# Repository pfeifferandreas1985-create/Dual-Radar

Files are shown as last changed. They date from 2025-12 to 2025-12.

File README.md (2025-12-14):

# NERO SENSE - Dual Radar System

**Nero Sense** is a high-tech, dual-system radar dashboard designed for environmental scanning and visualization. It combines an Ultrasonic Radar (System A) and a TOF Lidar (System B) into a unified "Tactical Dashboard" web interface.

## 🚀 Features

*   **Dual System Support**:
    *   **System A (Ultrasonic)**: Long-range, multi-sensor scanning (HC-SR04).
    *   **System B (TOF Lidar)**: High-precision, fast scanning (VL53L1X) with local display.
*   **Tactical Dashboard**: A futuristic web interface (HTML5/Canvas) featuring:
    *   **TRON & Matrix Themes**: Distinct visual styles for each system.
    *   **Real-time Visualization**: Smooth radar sweep, persistent object detection, and fading trails.
    *   **Dynamic Scaling**: Adjustable range controls (Zoom).
    *   **Telemetry**: Live distance and angle readouts.
*   **Hybrid Mode (System B)**: The TOF unit operates as a standalone device with a local **GC9A01 Circular Display**, showing a "Tactical Grid" and data even without WiFi.

---

## 🛠 Hardware & Wiring

### System B: TOF Lidar (Hybrid Unit)
*   **MCU**: Wemos D1 Mini (ESP8266)
*   **Sensor**: VL53L1X (TOF0400)
*   **Display**: 1.28" GC9A01 Circular TFT (240x240)
*   **Actuator**: Micro Servo (SG90)

#### Wiring Diagram
| Component | Pin | Wemos D1 Mini (GPIO) |
| :--- | :--- | :--- |
| **GC9A01** | **SCLK** | **D5** (GPIO 14) |
| | **MOSI** | **D7** (GPIO 13) |
| | **CS** | **D8** (GPIO 15) |
| | **DC** | **D3** (GPIO 0) |
| | **RST** | **D0** (GPIO 16) |
| | **VCC** | 3.3V |
| | **GND** | GND |
| **VL53L1X** | **SDA** | **D2** (GPIO 4) |
| | **SCL** | **D1** (GPIO 5) |
| | **VCC** | 3.3V |
| | **GND** | GND |
| **Servo** | **Signal** | **D6** (GPIO 12) |
| | **VCC** | 5V |
| | **GND** | GND |

---

## 💾 Firmware Installation

### Prerequisites
1.  **Arduino IDE**: Install the latest version.
2.  **ESP8266 Board Manager**: Install `esp8266` by ESP8266 Community.
3.  **Libraries**: Install via Library Manager:
    *   `TFT_eSPI` by Bodmer
    *   `VL53L1X` by Pololu
    *   `WebSockets` by Markus Sattler
    *   `Servo` (Built-in)

### Configuration (Critical!)
You **MUST** configure the `TFT_eSPI` library to work with the GC9A01 and Wemos D1 Mini pins.
1.  Go to your Arduino libraries folder: `Documents/Arduino/libraries/TFT_eSPI/`
2.  Edit `User_Setup.h`.
3.  Replace its content with the settings found in: `Firmware/Nereo_Sense_Hybrid_Wemos/User_Setup_Wemos.txt`

### Uploading
1.  Open `Firmware/Nereo_Sense_Hybrid_Wemos/Nero_Sense_Hybrid_Wemos.ino`.
2.  Set your WiFi SSID and Password in the code (if not already set).
3.  Select Board: **LOLIN(WEMOS) D1 R2 & mini**.
4.  Upload!

---

## 🖥️ Dashboard Usage

1.  **Open the Dashboard**: Open `Software/Dashboard/TRON_Radar.html` in any modern web browser.
2.  **Connect**:
    *   Enter the IP address of System A (Default: `192.168.178.70`).
    *   Enter the IP address of System B (Default: `192.168.178.41`).
    *   Click **CONNECT**.
3.  **Controls**:
    *   **Range**: Adjust the input field (e.g., "50" cm or "1000" mm) to zoom in/out.
    *   **Visuals**: Enjoy the show!

---

## 📂 Repository Structure

*   `Docs/`: Documentation files.
*   `Firmware/`: Arduino source code.
    *   `Nereo_Sense_Hybrid_Wemos/`: Firmware for System B (TOF).
    *   `LidarRadar/`: Firmware for System A (Ultrasonic).
*   `Hardware/`: CAD files and 3D models.
*   `Software/`: PC-side software.
    *   `Dashboard/`: The HTML5 Web Interface.

---

**Nero Sense Project** - *Advanced Environmental Awareness*

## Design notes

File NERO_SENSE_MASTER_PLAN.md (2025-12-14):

# NERO SENSE - MASTER PLAN
**System Architecture & Future Roadmap**

## 🟢 Variante 1: Das Aktuelle System (Scanning Lidar)
**Status: Operational**

Ein Sensor auf einem Servo, der die Umgebung abtastet und ein detailliertes Bild auf dem Display zeichnet.

### Verdrahtungsplan (Wemos D1 Mini)
Dies ist die finale Belegung für SPI-Display + I2C-Sensor + Servo.

| Komponente | Pin | Wemos D1 Mini Pin | Funktion |
| :--- | :--- | :--- | :--- |
| **Display** | SCLK | D5 (GPIO 14) | SPI Clock |
| | MOSI | D7 (GPIO 13) | SPI Data |
| | CS | D8 (GPIO 15) | Chip Select |
| | DC | D3 (GPIO 0) | Data/Command |
| | RST | D0 (GPIO 16) | Reset |
| **Sensor** | SCL | D1 (GPIO 5) | I2C Clock |
| | SDA | D2 (GPIO 4) | I2C Data |
| **Servo** | Signal | D6 (GPIO 12) | PWM Signal |
| **Power** | VCC/GND | 3.3V / GND | (Servo an 5V!) |

### Firmware Features (Final)
*   **Cinematic Boot**: "Nero Robotics" Intro mit Glitch-Effekt.
*   **Tron Visualization**: Verbundene Cyan-Linien (Wände) + Navy Schatten (Verdeckter Bereich).
*   **Smoothing**: Low-Pass-Filter für stabile Linien.
*   **Hybrid Network**: Statische IP `192.168.178.71` + Fallback auf Standalone.

### Der Prompt für Variante 1 (Backup)
*Dieser Prompt erstellt die finale Firmware mit "Nero" Intro, verbundenen Linien und Schatten-Effekt.*

```text
Role: Senior Firmware Architect for ESP8266.
Project: NERO SENSE - Single Node Scanning Lidar.
Hardware: Wemos D1 Mini, GC9A01 Display (Hardware SPI), VL53L1X (I2C), Servo.

Pin Config (TFT_eSPI compatible):
- Display: SCLK=D5, MOSI=D7, CS=D8, DC=D3, RST=D0.
- Sensor: SCL=D1, SDA=D2.
- Servo: D6.

Task: Write the complete Arduino Firmware.

Features:
1. Boot Animation:
   - Procedural "Apple-style" intro. Center dot expands to a cyan ring. Text "NERO" (White) and "ROBOTICS" (Cyan) appears.
2. Radar Logic (The "Tesla View"):
   - Servo sweeps 0-180 degrees using millis() (non-blocking). Step size: 1 degree.
   - Store readings in an array `distHistory[181]`.
   - Drawing Logic (Artifact Free & Correct Orientation):
     - **Orientation**: Use `angle` directly for radians (not `180-angle`) to match physical servo movement (Left=Left).
     - **Sector Clearing**: Before drawing, draw a Black Triangle from Center to (CurrentAngle, NextAngle) to wipe the path ahead.
     - **Explicit Erasure**: Draw a Black Line at the *previous* angle to ensure the old red scanner line is removed.
     - **Map Restoration**: Restore the "Shadow Zone" (Navy) and "Wall" (Cyan) at the previous angle *after* erasing the red line.
     - **Jump Filter**: Only connect wall points if distance difference < 150mm.
     - Draw Red Scanner Line on top.
   - Split Screen: Top half (0-120px) is Radar, Bottom half is large Digital Text (Distance/Angle).
3. Connectivity:
   - Static IP: 192.168.178.71.
   - Websocket Server broadcasting JSON {angle, distance}.

Output: Complete .ino code including User_Setup.h configuration comment.
```

---

## 🔵 Variante 2: Das Zukunfts-System (Quad-Core Static)
**Status: Concept / Next Step**

4 Sensoren, 90° versetzt (Vorne, Hinten, Links, Rechts). Keine beweglichen Teile (Servo).

### Die Herausforderung & Lösung
Du kannst am ESP8266 nicht einfach 4 TOF-Sensoren parallel anschließen, da alle die gleiche I2C-Adresse (0x29) haben.

**Die Hardware-Erweiterung:**
*   Du benötigst einen **I2C Multiplexer (TCA9548A)**.
*   Der ESP redet nur mit dem Multiplexer.
*   Der Multiplexer hat 8 Kanäle (SD0-SD7 / SC0-SC7).
*   Du schließt jeden Sensor an einen eigenen Kanal an.

### Verdrahtungsplan (Zukunft)

| Komponente | Pin | Geht an |
| :--- | :--- | :--- |
| **Multiplexer** | SDA / SCL | An Wemos D2 / D1 |
| **Display** | (Alle Pins) | Wie oben (D5, D7, D8, D3, D0) |
| **Sensor Vorne** | SDA / SCL | An Multiplexer Kanal 0 |
| **Sensor Rechts** | SDA / SCL | An Multiplexer Kanal 1 |
| **Sensor Hinten** | SDA / SCL | An Multiplexer Kanal 2 |
| **Sensor Links** | SDA / SCL | An Multiplexer Kanal 3 |

*(Servo entfällt, dafür hast du jetzt 360° Abdeckung ohne Mechanik)*

### Der Prompt für Variante 2 (Zukunft)
*Speichere diesen Prompt für später, wenn du den Multiplexer hast.*

```text
Role: Senior Firmware Architect for ESP8266.
Project: NERO SENSE - Quad Static Lidar (360°).
Hardware: Wemos D1 Mini, GC9A01 Display, TCA9548A Multiplexer, 4x VL53L1X Sensors.

Hardware Concept:
- No moving parts (Solid State).
- 4 Sensors mounted at 0° (Front), 90° (Right), 180° (Back), 270° (Left).
- Sensors connected via TCA9548A Multiplexer on Channels 0, 1, 2, 3.

Task: Write the complete Arduino Firmware.

Features:
1. Visualization (The "Shield View"):
   - Divide the round display into 4 quadrants.
   - Center of display represents the robot.
   - Visualize the distance of each sensor as a "Shield Bar" moving from the center outwards.
     - Close object = Bar close to center (Red).
     - Far object = Bar far from center (Cyan).
   - Display the exact distance in mm in each quadrant corner.
2. Multiplexer Logic:
   - Implement a function `tcaselect(uint8_t i)` to switch I2C channels before reading each sensor.
3. Boot Sequence:
   - "NERO SENSE 360" text intro.
   - Check all 4 sensors. If one fails, show error on screen.
4. Connectivity:
   - Static IP: 192.168.178.42.
   - Websocket JSON: {front, right, back, left}.

Output: Complete .ino code. Use "Wire.h" and "VL53L1X.h".
```

---
*Generated by Antigravity for Nero Robotics*

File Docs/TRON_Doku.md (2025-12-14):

# TRON Radar Systems - Projektdokumentation

Diese Dokumentation fasst die Entwicklung der drei Systemkomponenten zusammen: das LIDAR-Radar, das Compound-Ultraschall-Radar und das vereinte TRON Command Center.

---

## 1. System A: Das LIDAR-Radar (TOF)
Ein hochpräzises Radar für feine Abtastungen im Nahbereich (bis 2m).

### Hardware
*   **Mikrocontroller:** ESP8266 (NodeMCU/Wemos D1 Mini)
*   **Sensor:** VL53L1X (Time-of-Flight Laser-Entfernungsmesser)
*   **Aktor:** Micro Servo (SG90 o.ä.)
*   **Verbindung:** I2C (SDA/SCL) für Sensor, PWM für Servo.

### Funktionsweise
*   **Scan-Bereich:** 180° (Halbkreis).
*   **Auflösung:** Millimeter-genau.
*   **Logik:** Der Servo schwenkt von 0° bis 180° und zurück. Bei jedem Schritt wird eine Laser-Messung durchgeführt.
*   **Datenübertragung:** Sendet JSON-Pakete (`{angle, distance}`) per WebSocket an den PC.

### Besonderheiten
*   Sehr präzise, aber nur ein einziger Messpunkt (Laserstrahl).
*   Visualisierung als "Scanner" mit verblassenden Punkten (roter "Schweif").

---

## 2. System B: Das Compound-Radar (Omni-Sonar)
Ein 360°-Rundumsicht-Radar für schnelle Raumerfassung.

### Hardware
*   **Mikrocontroller:** ESP8266
*   **Sensoren:** 4x HC-SR04 Ultraschall-Module.
*   **Aktor:** Micro Servo.
*   **Anordnung:** Die 4 Sensoren sind im 90°-Winkel zueinander montiert (Vorne, Hinten, Links, Rechts).

### Funktionsweise
*   **Sektor-Scan:** Der Servo dreht sich nur von **40° bis 140°** (100° Sektor).
*   **360° Abdeckung:** Da die Sensoren versetzt sind, deckt dieser kleine Schwenk den gesamten Raum ab (4x 90° = 360°).
*   **Interleaved Sampling:** Um Geschwindigkeit zu gewinnen, werden die Sensoren versetzt abgefragt (Front -> Links -> Back -> Rechts). Die Messzeit der einen Gruppe dient als Abkühlzeit der anderen.
*   **Geschwindigkeitsregelung:** Über einen Slider im Dashboard kann die Drehgeschwindigkeit (Pause zwischen Schritten) eingestellt werden.
*   **WiFi-Fix:** Nutzt `WiFi.setSleepMode(WIFI_NONE_SLEEP)`, um Servo-Zittern durch Stromspitzen zu verhindern.

### Besonderheiten
*   Erstellt eine **persistente Karte** (Map Mode) des Raumes.
*   Punkte bleiben dauerhaft stehen und bilden Wände als feine Linien (1px) ab.
*   Enorme Scan-Geschwindigkeit durch Sektor-Optimierung.

---

## 3. System C: Unified TRON Command Center
Die zentrale Steuereinheit, die beide Radarsysteme vereint.

### Technologie
*   **Plattform:** Web-basiert (HTML5, CSS3, JavaScript).
*   **Rendering:** Hardware-beschleunigtes Canvas API.
*   **Kommunikation:** Duale WebSocket-Clients (verbindet sich gleichzeitig mit beiden ESPs).
*   **Design:** "TRON Legacy" Ästhetik (Neon-Blau & Neon-Orange auf Schwarz, Grid-Lines).

### Features
*   **System Link:** Start-Modal zur Eingabe der IP-Adressen beider Radare.
*   **Dual Scope:**
    *   **Links (Blau):** 360° Ansicht des Ultraschall-Radars. Zeigt Live-Werte (cm) und eine dauerhafte Karte.
    *   **Rechts (Orange):** 180° Ansicht des LIDARs. Zeigt präzise Scans mit Nachleucht-Effekt.
*   **Interaktive Steuerung:**
    *   Geschwindigkeits-Slider für das Ultraschall-Radar.
    *   "Reset Map" Button zum Löschen der Karte.
*   **HUD:** Head-Up-Display mit Live-Daten, Status-Anzeigen (ONLINE/OFFLINE) und Richtungsbeschriftungen (FRONT, BACK, LEFT, RIGHT).

### Deployment
*   Das System liegt als ausführbare Datei (`TRON_Radar.html`) auf dem Desktop und kann ohne Installation gestartet werden.

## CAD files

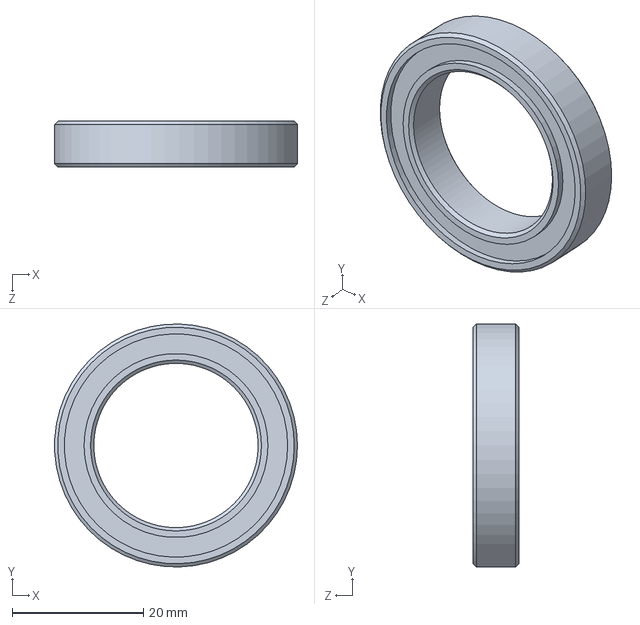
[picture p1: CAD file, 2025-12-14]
Hardware/CAD/Source_Files/lager.SLDPRT
37.0 x 37.0 x 7.00 mm

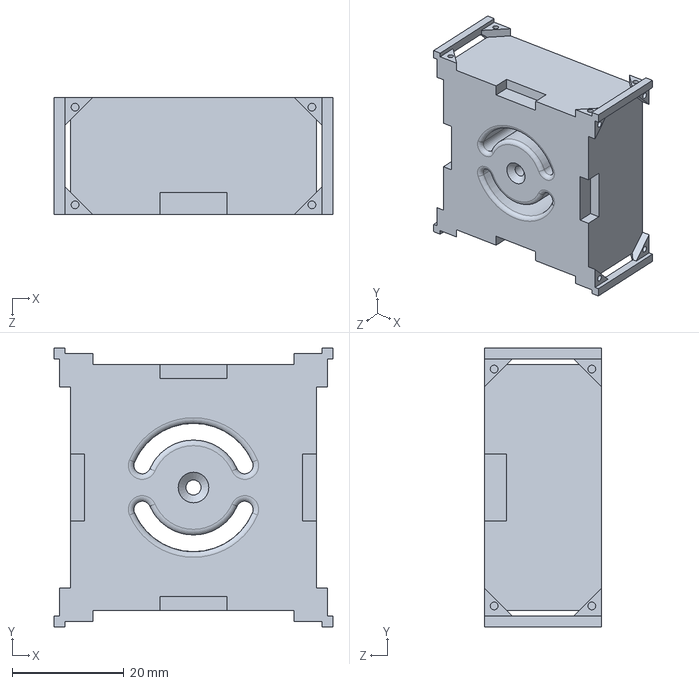
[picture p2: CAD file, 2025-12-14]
Hardware/CAD/Source_Files/Radarahmen.SLDPRT
50.0 x 50.0 x 21.0 mm

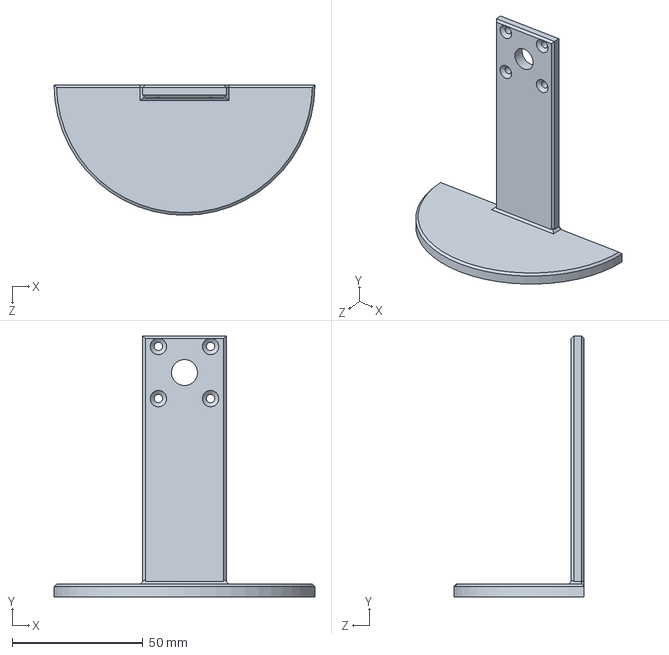
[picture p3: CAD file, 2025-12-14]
Hardware/CAD/Source_Files/Testhalter.SLDPRT
100.0 x 100.0 x 50.0 mm

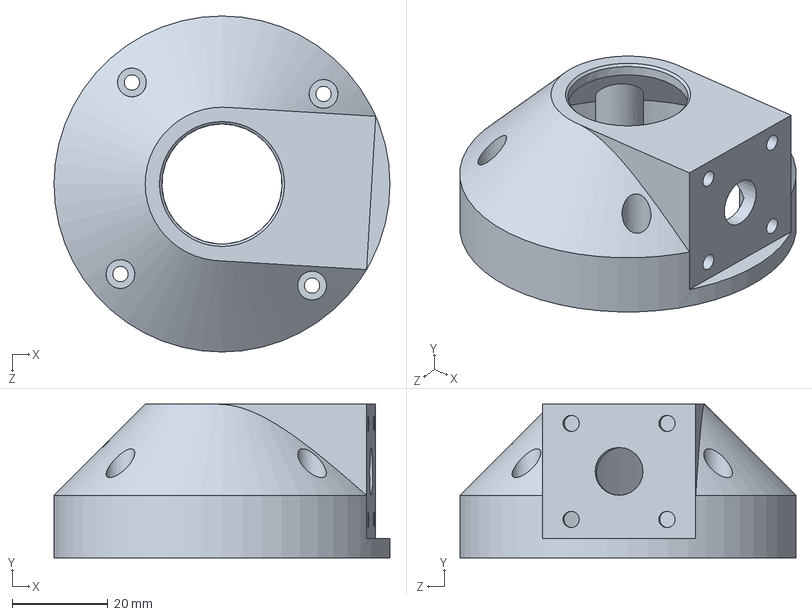
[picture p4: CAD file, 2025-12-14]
Hardware/CAD/Source_Files/Lidarkappe.SLDPRT
70.0 x 32.0 x 70.0 mm

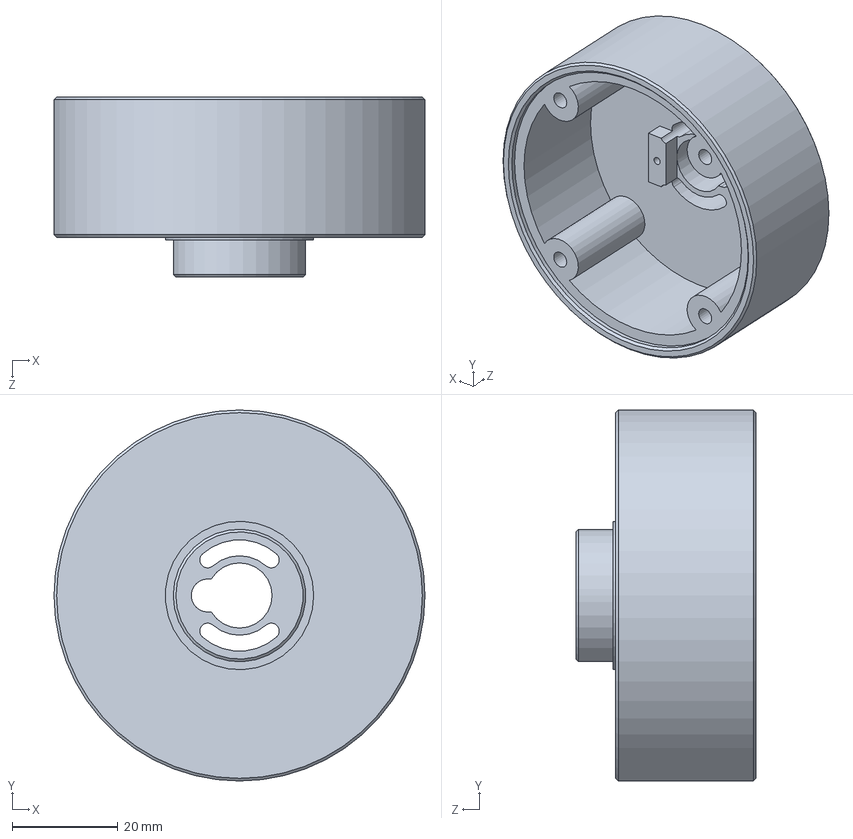
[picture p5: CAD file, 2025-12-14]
Hardware/CAD/Source_Files/Gehaeuse.SLDPRT
70.0 x 70.0 x 34.0 mm

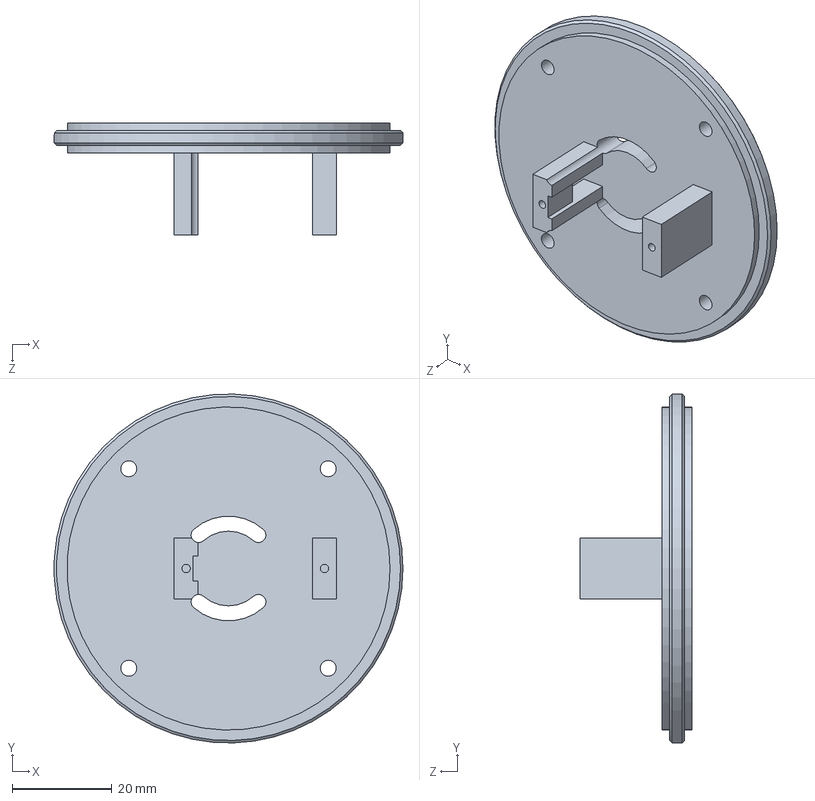
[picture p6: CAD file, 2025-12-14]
Hardware/CAD/Source_Files/LidarHalter.SLDPRT
70.0 x 70.0 x 22.5 mm

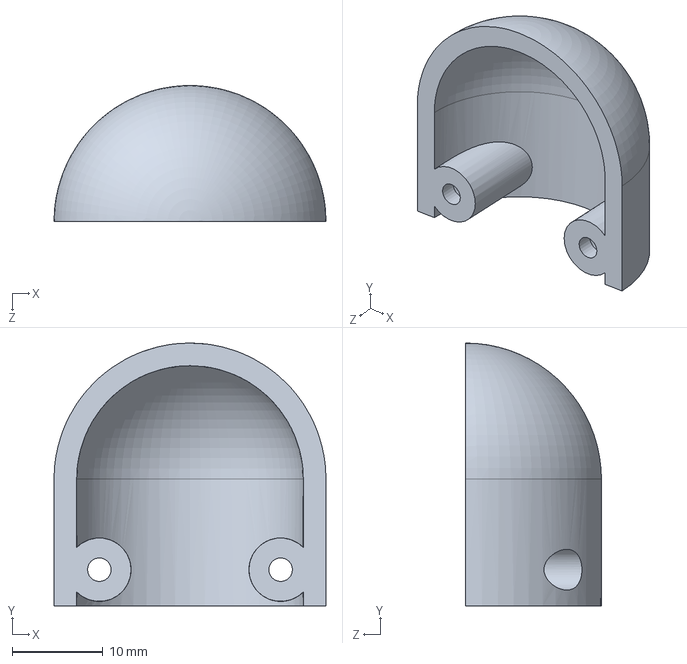
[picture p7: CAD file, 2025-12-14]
Hardware/CAD/Source_Files/Scannerhead_Abdeckung.SLDPRT
30.0 x 29.0 x 15.0 mm

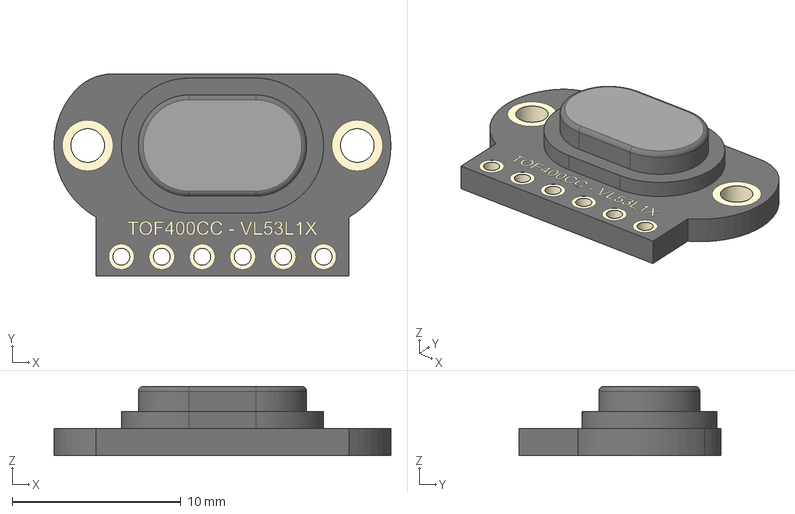
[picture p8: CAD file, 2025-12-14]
Hardware/CAD/Source_Files/TOF400MM.iges
20.0 x 12.0 x 4.11 mm

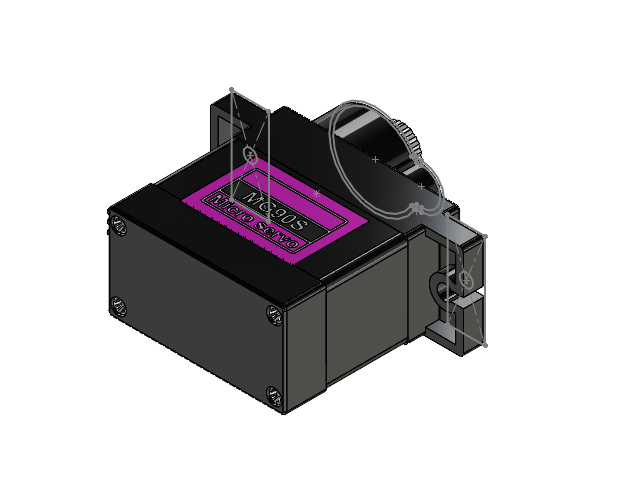
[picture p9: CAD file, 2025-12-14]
Hardware/CAD/Source_Files/Assembly SERVO.SLDASM
Assembly servo inside.stp
Assembly servo outside.stp

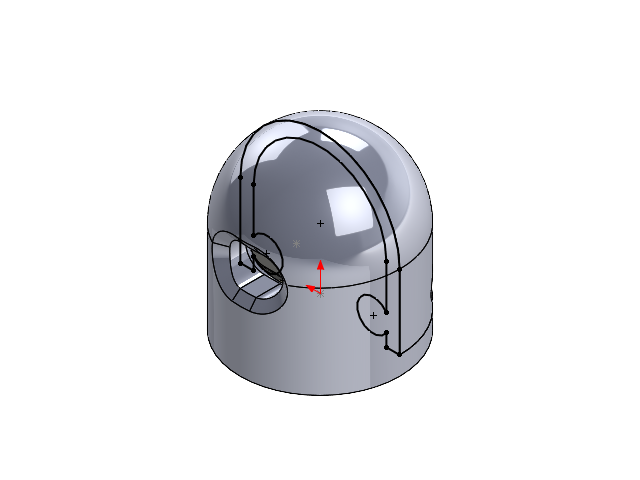
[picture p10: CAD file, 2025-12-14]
Hardware/CAD/Source_Files/Scannerhead.SLDASM
Scannerhead
TOF400MM.iges
Scannerhead_Abdeckung

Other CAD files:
Hardware/CAD/Gehaeuse.3MF
Hardware/CAD/LidarHalter.3mf
Hardware/CAD/Lidarkappe.3MF
Hardware/CAD/Radarahmen.3MF
Hardware/CAD/Scannerhead.3MF
Hardware/CAD/Scannerhead_Abdeckung.3MF
Hardware/CAD/Source_Files/Scannerhead.SLDPRT
Hardware/CAD/Testhalter.3mf

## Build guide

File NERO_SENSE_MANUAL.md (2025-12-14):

# NERO SENSE - SYSTEM B (Lidar Radar)
**High-Performance Tactical Radar Unit**

## 1. Overview
The **Nero Sense System B** is a standalone, high-precision radar unit designed for the Nero Robotics ecosystem. It utilizes a **Time-of-Flight (TOF) Laser Sensor** to map its surroundings with millimeter accuracy and displays the data on a circular **Retina-Grade IPS Display**.

## 2. Hardware Specs
*   **MCU**: Wemos D1 Mini (ESP8266) @ 80MHz
*   **Display**: 1.28" Round IPS LCD (GC9A01 Driver) - 240x240 px
*   **Sensor**: VL53L1X (TOF0400C) Laser Distance Sensor (Range: 4m)
*   **Actuator**: SG90 Micro Servo (Modified for 180° sweep)

## 3. Wiring Configuration
| Component | Pin Name | Wemos Pin | Description |
| :--- | :--- | :--- | :--- |
| **Display** | VCC | 3.3V | Power |
| | GND | GND | Ground |
| | SCL | D5 (GPIO 14) | SPI Clock |
| | SDA | D7 (GPIO 13) | SPI MOSI |
| | RES | D0 (GPIO 16) | Reset |
| | DC | D3 (GPIO 0) | Data/Command |
| | CS | D8 (GPIO 15) | Chip Select |
| **Sensor** | VCC | 3.3V | Power |
| | GND | GND | Ground |
| | SDA | D2 (GPIO 4) | I2C Data |
| | SCL | D1 (GPIO 5) | I2C Clock |
| **Servo** | PWM | D6 (GPIO 12) | Control Signal |
| | VCC | 5V | Power (Direct from USB) |
| | GND | GND | Ground |

## 4. Firmware Features (Final Version)

### A. Cinematic Boot Sequence
A procedural animation sequence that plays on startup:
1.  **Singularity**: A single white pixel expands.
2.  **Pulse**: Organic "heartbeat" animation.
3.  **Ignition**: Cyan ring wipe clears the screen.
4.  **Identity**: "NERO ROBOTICS" logo with glitch effect.
5.  **Flash**: White screen flash before radar activation.

### B. "Tron" Visualization Engine
*   **Connected Contours**: Instead of drawing unconnected dots, the engine draws continuous **Cyan Lines** connecting measurement points, creating a solid "wall" effect.
*   **Jump Filter**: Prevents connecting foreground objects to background walls (Threshold: 300mm).
*   **Hatched Shadows**: Casts dark **Navy Blue** shadow lines behind detected objects to the edge of the screen, simulating occlusion.
*   **Data Smoothing**: Implements a **Low Pass Filter** (70% Old / 30% New) to eliminate sensor jitter and create fluid motion.
*   **Active Clearing**: The red scanner line actively wipes old data before drawing new readings.

### C. Hybrid Network Manager
*   **Static IP**: `192.168.178.71` (Gateway: `192.168.178.1`)
*   **Fallback Mode**: Attempts to connect for 5 seconds. If WiFi fails, it seamlessly switches to **Standalone Mode** (Red Dot) without blocking the radar loop.
*   **WebSocket**: Broadcasts JSON data `{"angle": X, "distance": Y}` to the Nero Dashboard.

### D. Stability Systems
*   **I2C Bus Reset**: Manually toggles the SCL line on startup to unstick any frozen I2C slaves.
*   **Retry Loop**: Attempts to initialize the sensor 5 times before reporting a failure.
*   **Watchdog Prevention**: Uses non-blocking `millis()` timers for all servo and sensor operations.

## 5. Installation
1.  **Install Libraries** (via Arduino Library Manager):
    *   `TFT_eSPI` (Bodmer)
    *   `VL53L1X` (Pololu)
    *   `Servo` (Built-in)
    *   `WebSockets` (Markus Sattler)
2.  **Configure TFT_eSPI**:
    *   Edit `User_Setup.h` in the library folder.
    *   Select `GC9A01_DRIVER`.
    *   Map pins as shown in the Wiring section.
3.  **Upload**:
    *   Board: "LOLIN(WEMOS) D1 R2 & mini"
    *   Upload Speed: 921600
    *   Flash Size: 4MB (FS:2MB OTA:~1019KB)

---
*Generated by Antigravity for Nero Robotics*
*Date: 2025-12-14*

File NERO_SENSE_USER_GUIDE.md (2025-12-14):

# NERO SENSE - SYSTEM B: OPERATIONAL GUIDE
**Advanced Capabilities & User Manual**

## 1. System Philosophy
The **Nero Sense System B** is not just a distance sensor; it is a **Tactical Environmental Awareness Unit**. Unlike simple ultrasonic sensors, it provides a high-resolution, 180-degree cross-section of the world, visualized in real-time with a "Tron-inspired" aesthetic. It bridges the gap between raw sensor data and human-readable tactical information.

## 2. Visual Interface: How to Read the Screen
The circular display is designed for instant readability:

*   **The Cyan Wall (Contours)**:
    *   This continuous blue line represents physical obstacles.
    *   **Smooth Curves**: Indicate flat walls or large objects.
    *   **Jagged Edges**: Indicate complex geometry or scattered objects.
    *   *Capability*: Allows you to instantly see the shape of a room or corridor.

*   **The Shadow Zone (Dark Navy)**:
    *   The dark lines extending from the "Wall" to the edge of the screen represent **Occluded Space**.
    *   This is the "Unknown" area behind an object.
    *   *Capability*: Helps in understanding blind spots. If a shadow moves, the object is moving.

*   **The Scanner (Red Laser)**:
    *   Shows the current active measurement angle.
    *   *Capability*: Verifies that the system is live and scanning.

*   **The Dashboard**:
    *   **Center**: Exact distance in millimeters to the object at the current angle.
    *   **Bottom**: Current Angle (0-180°).
    *   **Status Dot**: Green (Networked) / Red (Standalone).

## 3. Operational Modes

### A. Standalone Mode (Red Dot)
*   **Description**: The unit operates without WiFi.
*   **Use Case**: Handheld scanning, field deployment, or visual-only monitoring.
*   **Capability**:
    *   **Portable Scanner**: Power via USB power bank. Walk around a room to "see" in the dark.
    *   **Alignment Tool**: Use the precise mm readout to align objects or measure gaps.

### B. Networked Mode (Green Dot)
*   **Description**: The unit connects to the "Nero Network" (FRITZ!Box) and broadcasts data.
*   **Use Case**: Robotics integration, remote monitoring, home automation.
*   **Capability**:
    *   **IoT Sensor**: Can trigger events in Home Assistant (e.g., "If distance < 50cm, turn on light").
    *   **Remote Eyes**: View the radar data on a PC dashboard (via `TRON_Radar.html`).

## 4. Integration & API (For Developers)
The true power of Nero Sense lies in its **WebSocket API**. It broadcasts raw data in real-time, allowing external systems to "tap in".

**Connection Details:**
*   **IP**: `192.168.178.71`
*   **Port**: `81`
*   **Protocol**: WebSocket (WS)

**Data Format (JSON):**
```json
{
  "angle": 45,      // Current Servo Angle (0-180)
  "distance": 1250  // Distance in millimeters
}
```

### Python Integration Example
You can control a robot based on this data. Here is a snippet for a "Collision Avoidance" script:

```python
import websocket
import json

def on_message(ws, message):
    data = json.loads(message)
    angle = data['angle']
    dist = data['distance']
    
    # Simple Logic: If obstacle ahead is close, STOP.
    if 70 < angle < 110 and dist < 300:
        print(f"CRITICAL: Obstacle at {dist}mm! STOP ROBOT!")
        # robot.stop()

ws = websocket.WebSocketApp("ws://192.168.178.71:81/", on_message=on_message)
ws.run_forever()
```

## 5. Advanced Use Cases

### 1. Hexapod Navigation (SLAM)
Mount the Nero Sense on the **Nero Hexapod**.
*   **Capability**: The robot can scan its environment to build a 2D map.
*   **Logic**: Combine the Radar Angle + Robot Rotation to create a 360° map (SLAM).

### 2. Security Tripwire
Place the unit facing a doorway.
*   **Capability**: Detect intruders.
*   **Logic**: If the "Wall" suddenly changes distance (e.g., from 2000mm to 500mm), someone has walked through.

### 3. Object Profiling
Place an object on a turntable in front of the sensor.
*   **Capability**: 3D Scanning (Basic).
*   **Logic**: Record distance profiles as the object rotates to reconstruct its shape digitally.

---
*Nero Robotics - Advanced Systems Division*

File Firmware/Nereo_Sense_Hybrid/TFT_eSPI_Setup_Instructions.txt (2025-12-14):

// ============================================================================
// TFT_eSPI LIBRARY CONFIGURATION FOR NEREO SENSE (ESP-12F + GC9A01)
// ============================================================================
// Locate the 'User_Setup.h' file in your Arduino libraries folder:
// Path: Documents/Arduino/libraries/TFT_eSPI/User_Setup.h
//
// REPLACE the contents or UNCOMMENT/EDIT the following lines:

#define USER_SETUP_INFO "Nereo_Sense_GC9A01"

// 1. Driver
#define GC9A01_DRIVER

// 2. Pin Definitions (ESP8266 / ESP-12F)
// ---------------------------------------
// SCLK: GPIO 14
// MOSI: GPIO 13
// CS:   GPIO 15
// DC:   GPIO 0
// RST:  GPIO 16

#define TFT_MISO  -1  // Not used
#define TFT_MOSI  13
#define TFT_SCLK  14
#define TFT_CS    15
#define TFT_DC    0
#define TFT_RST   16

// 3. Fonts
#define LOAD_GLCD   // Font 1. Original Glcd font
#define LOAD_FONT2  // Font 2. Small 16 pixel high font
#define LOAD_FONT4  // Font 4. Medium 26 pixel high font
#define LOAD_FONT6  // Font 6. Large 48 pixel font
#define LOAD_GFXFF  // FreeFonts. Include access to the 48 Adafruit_GFX free fonts FF1 to FF48

#define SMOOTH_FONT

// 4. SPI Frequency
#define SPI_FREQUENCY  27000000 // 27MHz is usually stable for GC9A01
// #define SPI_FREQUENCY  40000000 // Try 40MHz if stable for higher FPS

// ============================================================================

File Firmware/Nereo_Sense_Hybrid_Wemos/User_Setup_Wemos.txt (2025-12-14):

// ============================================================================
// TFT_eSPI LIBRARY CONFIGURATION FOR NERO SENSE (WEMOS D1 MINI + GC9A01)
// ============================================================================
// Locate the 'User_Setup.h' file in your Arduino libraries folder:
// Path: Documents/Arduino/libraries/TFT_eSPI/User_Setup.h
//
// REPLACE the contents or UNCOMMENT/EDIT the following lines:

#define USER_SETUP_INFO "Nero_Sense_Wemos_GC9A01"

// 1. Driver
#define GC9A01_DRIVER

// 2. Pin Definitions (Wemos D1 Mini / ESP8266)
// --------------------------------------------
// TFT_SCLK (CLK): Pin D5 (GPIO 14)
// TFT_MOSI (DIN): Pin D7 (GPIO 13)
// TFT_CS   (CS):  Pin D8 (GPIO 15)
// TFT_DC   (DC):  Pin D3 (GPIO 0)
// TFT_RST  (RST): Pin D0 (GPIO 16)

#define TFT_MISO  -1  // Not used
#define TFT_MOSI  13  // D7
#define TFT_SCLK  14  // D5
#define TFT_CS    15  // D8
#define TFT_DC    0   // D3
#define TFT_RST   16  // D0

// 3. Fonts
#define LOAD_GLCD   // Font 1. Original Glcd font
#define LOAD_FONT2  // Font 2. Small 16 pixel high font
#define LOAD_FONT4  // Font 4. Medium 26 pixel high font
#define LOAD_FONT6  // Font 6. Large 48 pixel font
#define LOAD_GFXFF  // FreeFonts. Include access to the 48 Adafruit_GFX free fonts FF1 to FF48

#define SMOOTH_FONT

// 4. SPI Frequency
#define SPI_FREQUENCY  27000000 // 27MHz
// #define SPI_FREQUENCY  40000000 // Try 40MHz if stable

// ============================================================================

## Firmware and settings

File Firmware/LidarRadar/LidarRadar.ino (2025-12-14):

/*
 * TRON Style LIDAR Radar System
 * Hardware: ESP-12F, VL53L1X, Micro Servo
 * 
 * Wiring:
 *  - VL53L1X SDA: GPIO 4
 *  - VL53L1X SCL: GPIO 5
 *  - Servo Signal: GPIO 14
 *  - Status LED:   GPIO 2 (Built-in, Active Low)
 *  
 * Libraries required:
 *  - VL53L1X (Pololu)
 *  - WebSockets (Markus Sattler)
 *  - Servo (Built-in)
 *  - ESP8266WiFi (Built-in)
 */

#include <ESP8266WiFi.h>
#include <WebSocketsServer.h>
#include <ESP8266WebServer.h>
#include <Wire.h>
#include <VL53L1X.h>
#include <Servo.h>

// ===================================================================================
// CONFIGURATION
// ===================================================================================
const char* ssid     = "ESP-RADAR";
const char* password = "password123"; // Set to NULL for open network

const int PIN_SDA   = 4;
const int PIN_SCL   = 5;
const int PIN_SERVO = 14;
const int PIN_LED   = 2;

// Servo Settings
const int SERVO_MIN_ANGLE = 0;
const int SERVO_MAX_ANGLE = 180;
int servoDelay = 15; // ms between steps (controls sweep speed) - Dynamic

// Sensor Settings
#define SENSOR_BUDGET 20000 // us (20ms)

// ===================================================================================
// GLOBALS
// ===================================================================================
VL53L1X sensor;
Servo scanner;
WebSocketsServer webSocket = WebSocketsServer(81);
ESP8266WebServer server(80);

int currentAngle = 90;
int angleStep = 1;
unsigned long lastServoMove = 0;
bool longRangeMode = false;

// ===================================================================================
// FRONTEND (HTML/CSS/JS)
// ===================================================================================
const char index_html[] PROGMEM = R"=====(
<!DOCTYPE html>
<html lang="en">
<head>
<meta charset="UTF-8">
<meta name="viewport" content="width=device-width, initial-scale=1.0, maximum-scale=1.0, user-scalable=no">
<title>TRON LIDAR</title>
<style>
  :root {
    --bg-color: #000000;
    --grid-color: #1a1a1a;
    --primary-color: #00FFFF;
    --alert-color: #FF0000;
    --panel-bg: rgba(0, 20, 20, 0.8);
  }
  body { 
    margin: 0; 
    background: var(--bg-color); 
    overflow: hidden; 
    font-family: 'Segoe UI', 'Roboto', monospace; 
    color: var(--primary-color);
    user-select: none;
  }
  #radar-container { 
    position: relative; 
    width: 100vw; 
    height: 100vh; 
    display: flex; 
    justify-content: center; 
    align-items: center; 
  }
  canvas { 
    border-radius: 50%; 
    background: radial-gradient(circle, #001111 0%, #000000 90%); 
    box-shadow: 0 0 30px rgba(0, 255, 255, 0.1);
  }
  .hud { 
    position: absolute; 
    top: 20px; 
    left: 20px; 
    z-index: 10; 
    pointer-events: none; 
    text-shadow: 0 0 5px var(--primary-color);
  }
  .controls {
    position: absolute;
    bottom: 20px;
    left: 50%;
    transform: translateX(-50%);
    z-index: 20;
    background: var(--panel-bg);
    padding: 15px;
    border: 1px solid var(--primary-color);
    border-radius: 10px;
    display: flex;
    gap: 20px;
    align-items: center;
    box-shadow: 0 0 15px rgba(0, 255, 255, 0.2);
    backdrop-filter: blur(5px);
  }
  h1 { margin: 0; font-size: 20px; letter-spacing: 2px; border-bottom: 1px solid var(--primary-color); display: inline-block; padding-bottom: 5px; }
  .data-row { margin-top: 10px; font-size: 14px; font-family: 'Courier New', monospace; }
  .label { opacity: 0.7; margin-right: 10px; }
  .value { font-weight: bold; font-size: 16px; }
  #status { font-weight: bold; color: var(--alert-color); }
  #status.connected { color: #00FF00; text-shadow: 0 0 5px #00FF00; }
  
  /* Inputs */
  button {
    background: transparent;
    border: 1px solid var(--primary-color);
    color: var(--primary-color);
    padding: 8px 16px;
    font-family: inherit;
    font-weight: bold;
    cursor: pointer;
    text-transform: uppercase;
    transition: all 0.2s;
  }
  button:hover { background: rgba(0, 255, 255, 0.2); box-shadow: 0 0 10px var(--primary-color); }
  button:active { transform: scale(0.95); }
  
  input[type=range] {
    -webkit-appearance: none;
    background: transparent;
    width: 150px;
  }
  input[type=range]::-webkit-slider-thumb {
    -webkit-appearance: none;
    height: 16px; width: 16px;
    border-radius: 50%;
    background: var(--primary-color);
    cursor: pointer;
    margin-top: -6px;
    box-shadow: 0 0 10px var(--primary-color);
  }
  input[type=range]::-webkit-slider-runnable-track {
    width: 100%; height: 4px;
    background: #333;
    border-radius: 2px;
  }
  
  .control-group { display: flex; flex-direction: column; align-items: center; }
  .control-label { font-size: 10px; margin-bottom: 5px; opacity: 0.8; }

  /* Scan line effect overlay */
  .scan-overlay {
    position: absolute;
    top: 0; left: 0; right: 0; bottom: 0;
    background: linear-gradient(to bottom, rgba(0,255,255,0), rgba(0,255,255,0.05) 50%, rgba(0,255,255,0));
    background-size: 100% 4px;
    pointer-events: none;
    z-index: 5;
  }
</style>
</head>
<body>
<div class="hud">
  <h1>TRON_LIDAR_SYSTEM</h1>
  <div class="data-row"><span class="label">LINK:</span><span id="status">OFFLINE</span></div>
  <div class="data-row"><span class="label">AZIMUTH:</span><span id="angle" class="value">0</span>&deg;</div>
  <div class="data-row"><span class="label">RANGE:</span><span id="dist" class="value">0</span> mm</div>
  <div class="data-row"><span class="label">MODE:</span><span id="modeDisplay" class="value">SHORT</span></div>
</div>

<div class="controls">
  <div class="control-group">
    <span class="control-label">SCAN SPEED</span>
    <!-- Reverse logic: Lower delay = Higher speed. Slider: 5 (Fast) to 100 (Slow) -->
    <!-- Let's make the slider intuitive: Left(Slow) -> Right(Fast). 
         Value 0-100. Map to Delay 100-5. -->
    <input type="range" id="speedSlider" min="0" max="100" value="80">
  </div>
  <div class="control-group">
    <span class="control-label">SENSOR RANGE</span>
    <button id="rangeBtn" onclick="toggleRange()">SHORT (1.3m)</button>
  </div>
</div>

<div class="scan-overlay"></div>
<div id="radar-container">
  <canvas id="radar"></canvas>
</div>
<script>
  const canvas = document.getElementById('radar');
  const ctx = canvas.getContext('2d');
  const statusEl = document.getElementById('status');
  const angleEl = document.getElementById('angle');
  const distEl = document.getElementById('dist');
  const modeDisplay = document.getElementById('modeDisplay');
  const rangeBtn = document.getElementById('rangeBtn');
  const speedSlider = document.getElementById('speedSlider');

  let width, height, centerX, centerY, maxRadius;
  const points = []; 
  let maxDist = 1500; // Default Short
  let ws;

  function resize() {
    width = window.innerWidth;
    height = window.innerHeight;
    canvas.width = width;
    canvas.height = height;
    centerX = width / 2;
    centerY = height / 2;
    maxRadius = Math.min(width, height) / 2 - 40;
  }
  window.addEventListener('resize', resize);
  resize();

  // WebSocket Connection
  function connect() {
    ws = new WebSocket('ws://' + location.hostname + ':81/');
    ws.onopen = () => { 
      statusEl.textContent = "ESTABLISHED"; 
      statusEl.classList.add('connected'); 
    };
    ws.onclose = () => { 
      statusEl.textContent = "LOST - RETRYING"; 
      statusEl.classList.remove('connected'); 
      setTimeout(connect, 2000);
    };
    ws.onmessage = (event) => {
      try {
        const data = JSON.parse(event.data);
        angleEl.textContent = data.angle;
        distEl.textContent = data.distance;
        
        points.push({
          angle: data.angle,
          dist: data.distance,
          time: Date.now()
        });
      } catch(e) {}
    };
  }
  connect();

  // Controls
  let isLongRange = false;
  function toggleRange() {
    isLongRange = !isLongRange;
    if (isLongRange) {
      ws.send('R1');
      rangeBtn.textContent = "LONG (4.0m)";
      modeDisplay.textContent = "LONG";
      maxDist = 4000;
    } else {
      ws.send('R0');
      rangeBtn.textContent = "SHORT (1.3m)";
      modeDisplay.textContent = "SHORT";
      maxDist = 1500;
    }
    // Clear old points to avoid confusion
    points.length = 0;
  }

  speedSlider.oninput = function() {
    // Map 0-100 to 100ms-5ms
    // 0 -> 100
    // 100 -> 5
    const val = parseInt(this.value);
    const delay = Math.floor(100 - (val * 0.95)); // Approx mapping
    if(ws && ws.readyState === WebSocket.OPEN) {
      ws.send('S' + delay);
    }
  };

  function drawGrid() {
    ctx.strokeStyle = '#1a1a1a';
    ctx.lineWidth = 1;
    ctx.beginPath();
    for (let r = 0.25; r <= 1; r += 0.25) {
      ctx.arc(centerX, centerY, maxRadius * r, 0, Math.PI * 2);
    }
    ctx.stroke();
    
    ctx.beginPath();
    ctx.moveTo(centerX - maxRadius, centerY);
    ctx.lineTo(centerX + maxRadius, centerY);
    ctx.moveTo(centerX, centerY - maxRadius);
    ctx.lineTo(centerX, centerY + maxRadius);
    ctx.stroke();
  }

  function draw() {
    ctx.fillStyle = 'rgba(0, 0, 0, 0.08)';
    ctx.fillRect(0, 0, width, height);

    drawGrid();

    const now = Date.now();
    
    for (let i = points.length - 1; i >= 0; i--) {
      const p = points[i];
      const age = now - p.time;
      if (age > 3000) {
        points.splice(i, 1);
        continue;
      }

      const rad = -(p.angle * Math.PI / 180);
      const r = (p.dist / maxDist) * maxRadius;
      const drawR = Math.min(r, maxRadius);

      const x = centerX + Math.cos(rad) * drawR;
      const y = centerY + Math.sin(rad) * drawR;

      const alpha = 1 - (age / 3000);
      
      ctx.beginPath();
      ctx.arc(x, y, 4, 0, Math.PI * 2);
      ctx.fillStyle = `rgba(0, 255, 255, ${alpha})`;
      
      if (age < 200) {
        ctx.shadowBlur = 15;
        ctx.shadowColor = '#00FFFF';
      } else {
        ctx.shadowBlur = 0;
      }
      
      ctx.fill();
      ctx.shadowBlur = 0;
    }
    
    requestAnimationFrame(draw);
  }
  draw();
</script>
</body>
</html>
)=====";

// ===================================================================================
// WEBSOCKET EVENT HANDLER
// ===================================================================================
void webSocketEvent(uint8_t num, WStype_t type, uint8_t * payload, size_t length) {
  if (type == WStype_TEXT) {
    // Command Parsing
    if (payload[0] == 'S') {
      // Speed Command: S<delay_ms>
      int val = atoi((const char*)&payload[1]);
      if (val < 5) val = 5;
      if (val > 200) val = 200;
      servoDelay = val;
    }
    else if (payload[0] == 'R') {
      // Range Command: R0 (Short) or R1 (Long)
      int val = atoi((const char*)&payload[1]);
      bool newMode = (val == 1);
      
      if (newMode != longRangeMode) {
        longRangeMode = newMode;
        
        // Reconfigure Sensor
        sensor.stopContinuous();
        delay(10); // Brief pause
        
        if (longRangeMode) {
          sensor.setDistanceMode(VL53L1X::Long);
          // Long mode needs more time budget
          sensor.setMeasurementTimingBudget(33000); 
        } else {
          sensor.setDistanceMode(VL53L1X::Short);
          sensor.setMeasurementTimingBudget(20000);
        }
        
        sensor.startContinuous(longRangeMode ? 33 : 20);
      }
    }
  }
}

// ===================================================================================
// SETUP
// ===================================================================================
void setup() {
  // 1. Init Pins
  pinMode(PIN_LED, OUTPUT);
  digitalWrite(PIN_LED, HIGH); // LED Off

  // 2. Init I2C
  Wire.begin(PIN_SDA, PIN_SCL);
  Wire.setClock(400000); // 400kHz I2C

  // 3. Init Sensor
  sensor.setTimeout(500);
  if (!sensor.init()) {
    // FAILURE: Rapid Blink
    while (1) {
      digitalWrite(PIN_LED, LOW);  delay(50);
      digitalWrite(PIN_LED, HIGH); delay(50);
    }
  }
  
  // Default: Short Mode
  sensor.setDistanceMode(VL53L1X::Short);
  sensor.setMeasurementTimingBudget(SENSOR_BUDGET);
  sensor.startContinuous(SENSOR_BUDGET / 1000);

  // 4. Init Servo
  scanner.attach(PIN_SERVO);
  scanner.write(currentAngle);

  // 5. Init WiFi (AP Mode)
  WiFi.mode(WIFI_AP);
  WiFi.softAP(ssid, password);

  // 6. Init Servers
  server.on("/", []() {
    server.send_P(200, "text/html", index_html);
  });
  server.begin();
  
  webSocket.begin();
  webSocket.onEvent(webSocketEvent);
}

// ===================================================================================
// LOOP
// ===================================================================================
void loop() {
  webSocket.loop();
  server.handleClient();

  unsigned long now = millis();

  // Non-blocking Servo Sweep
  if (now - lastServoMove >= servoDelay) {
    lastServoMove = now;
    
    // Update Angle
    currentAngle += angleStep;
    if (currentAngle >= SERVO_MAX_ANGLE || currentAngle <= SERVO_MIN_ANGLE) {
      angleStep = -angleStep; // Reverse direction
    }
    scanner.write(currentAngle);
    
    if (sensor.dataReady()) {
      uint16_t dist = sensor.read(false); // Non-blocking read
      
      // Broadcast JSON
      String json = "{\"angle\":";
      json += currentAngle;
      json += ",\"distance\":";
      json += dist;
      json += "}";
      webSocket.broadcastTXT(json);
    }
  }
}

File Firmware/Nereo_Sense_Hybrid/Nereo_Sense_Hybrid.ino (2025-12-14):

/*
 * NEREO SENSE HYBRID - SYSTEM B (TOF)
 * -----------------------------------
 * Hardware: ESP-12F, GC9A01 Display, TOF0400 (VL53L1X), Servo
 * Features: Hybrid Mode (WiFi/Offline), Circular Radar Viz, WebSocket
 */

#include <SPI.h>
#include <TFT_eSPI.h>       // Hardware-specific library
#include <Wire.h>
#include <VL53L1X.h>
#include <Servo.h>
#include <ESP8266WiFi.h>
#include <WebSocketsServer.h>

// --- CONFIGURATION ---
// Network
const char* ssid = "FRITZ!Box 6660 Cable UE";
const char* password = "YOUR_WIFI_PASSWORD"; // USER: PLEASE SET PASSWORD
IPAddress local_IP(192, 168, 178, 41);
IPAddress gateway(192, 168, 178, 1);
IPAddress subnet(255, 255, 255, 0);

// Pins
#define SERVO_PIN 12
#define SDA_PIN 4
#define SCL_PIN 5

// Radar Settings
#define MAX_DIST_MM 1000  // Max distance for visualization (1m)
#define ANGLE_MIN 0
#define ANGLE_MAX 180
#define ANGLE_STEP 2      // Degrees per step

// Colors (RGB565)
#define C_BLACK   0x0000
#define C_CYAN    0x07FF
#define C_GREEN   0x07E0
#define C_RED     0xF800
#define C_ORANGE  0xFD20
#define C_DARK    0x0022  // Very dark grey for fade

// --- OBJECTS ---
TFT_eSPI tft = TFT_eSPI();
VL53L1X sensor;
Servo myServo;
WebSocketsServer webSocket = WebSocketsServer(81);

// --- STATE ---
bool isOnline = false;
int currentAngle = 0;
int direction = 1; // 1 = up, -1 = down
unsigned long lastServoMove = 0;
int servoDelay = 15; // Speed control

// Radar Map (Simple persistence for fade effect)
// We store the distance at each angle to redraw/clear
uint16_t distMap[181]; 

void setup() {
  Serial.begin(115200);
  
  // 1. INIT DISPLAY
  tft.init();
  tft.setRotation(0); 
  tft.fillScreen(C_BLACK);
  
  // Boot Logo (Using built-in font to avoid SPIFFS error)
  tft.setTextDatum(MC_DATUM);
  tft.setTextColor(C_CYAN, C_BLACK);
  tft.setTextSize(2); 
  tft.drawString("NEREO SENSE", 120, 100);
  
  tft.setTextSize(1);
  tft.setTextColor(TFT_WHITE, C_BLACK);
  tft.drawString("System Init...", 120, 140);
  delay(1000);

  // 2. INIT SENSORS
  Wire.begin(SDA_PIN, SCL_PIN);
  Wire.setClock(400000);
  
  sensor.setTimeout(500);
  if (!sensor.init()) {
    tft.setTextColor(C_RED, C_BLACK);
    tft.drawString("SENSOR FAIL", 120, 160);
    Serial.println("Failed to detect and initialize sensor!");
    // Non-blocking error loop to prevent WDT reset
    while (1) { 
      yield(); // Feed the watchdog
      delay(100); 
    }
  }
  sensor.setDistanceMode(VL53L1X::Long);
  sensor.setMeasurementTimingBudget(15000); // 15ms
  sensor.startContinuous(15);

  myServo.attach(SERVO_PIN);

  // 3. CONNECTIVITY MANAGER
  tft.fillRect(0, 130, 240, 40, C_BLACK); // Clear text
  tft.drawString("Connecting WiFi...", 120, 140);
  
  WiFi.config(local_IP, gateway, subnet);
  WiFi.begin(ssid, password); // Note: Password needs to be set!

  unsigned long startAttempt = millis();
  bool connected = false;
  
  while (millis() - startAttempt < 10000) {
    if (WiFi.status() == WL_CONNECTED) {
      connected = true;
      break;
    }
    delay(100);
    // Loading bar?
    int bar = map(millis() - startAttempt, 0, 10000, 0, 100);
    tft.drawRect(70, 160, 100, 4, C_CYAN);
    tft.fillRect(70, 160, bar, 4, C_CYAN);
  }

  tft.fillScreen(C_BLACK);
  tft.setTextDatum(MC_DATUM);
  
  if (connected) {
    isOnline = true;
    tft.setTextColor(C_GREEN, C_BLACK);
    tft.drawString("ONLINE", 120, 120);
    tft.drawString(WiFi.localIP().toString(), 120, 140);
    webSocket.begin();
  } else {
    isOnline = false;
    tft.setTextColor(C_ORANGE, C_BLACK);
    tft.drawString("OFFLINE MODE", 120, 120);
  }
  
  delay(2000);
  tft.fillScreen(C_BLACK);
  
  // Draw Static Radar Grid
  drawGrid();
}

void loop() {
  if (isOnline) webSocket.loop();

  // Non-blocking Servo & Read Loop
  if (millis() - lastServoMove >= servoDelay) {
    lastServoMove = millis();
    
    // 1. Move Servo
    myServo.write(currentAngle);
    
    // 2. Read Sensor
    // Note: VL53L1X continuous mode reads in background, we just get latest
    sensor.read();
    uint16_t dist = sensor.ranging_data.range_mm;
    if (sensor.ranging_data.range_status != VL53L1X::RangeValid) {
      dist = 0; // Invalid
    }
    
    // 3. Update Map
    distMap[currentAngle] = dist;

    // 4. Visualize
    drawRadarLine(currentAngle, dist);
    
    // 5. Network Broadcast
    if (isOnline) {
      String json = "{\"angle\":" + String(currentAngle) + 
                    ",\"distance\":" + String(dist) + "}";
      webSocket.broadcastTXT(json);
    }

    // 6. Advance Angle
    currentAngle += direction * ANGLE_STEP;
    if (currentAngle >= ANGLE_MAX || currentAngle <= ANGLE_MIN) {
      direction *= -1;
    }
  }
}

// --- VISUALIZATION HELPERS ---

void drawGrid() {
  // Center (120, 120)
  tft.drawCircle(120, 120, 30, 0x0040); // Dark Green/Grey
  tft.drawCircle(120, 120, 60, 0x0040);
  tft.drawCircle(120, 120, 90, 0x0040);
  tft.drawCircle(120, 120, 119, C_CYAN); // Outer Ring
  
  tft.drawLine(0, 120, 240, 120, 0x0040); // Horizontal
  tft.drawLine(120, 0, 120, 240, 0x0040); // Vertical
}
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

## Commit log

2025-12-14 Final Firmware: Cinematic Boot, Tron Visualization, Stability Fixes
    [Nero_Sense_Hybrid_Wemos.ino]
2025-12-14 Final Polish: Smoothing Filter & Tron Contours
2025-12-14 Final Fix: Mirrored Visualization Corrected
    [Nero_Sense_Hybrid_Wemos.ino]
